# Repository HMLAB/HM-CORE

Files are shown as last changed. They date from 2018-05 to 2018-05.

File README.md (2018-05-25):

# 开源ZYNQ平台，加速你的创想
### Open source ZYNQ platform, accelerate your creativity.

1. Open Source PCB files for HM-CORE
2. Revision: V180401 - File Created
3. Hardware released under[ CERN OHL version 1.2](https://www.ohwr.org/licenses/cern-ohl/license_versions/v1.2 " CERN OHL version 1.2")
4. Forked and changed from https://github.com/AnttiLukats/HackaZynq
5. For more information, please visit: https://www.openzynq.org

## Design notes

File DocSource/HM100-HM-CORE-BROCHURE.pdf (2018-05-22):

HM-CORE Brochure

Powered by HMLAB (http://www.hm-lab.com/)

# HM-CORE

## 一段简单介绍

HM-CORE开源SOC硬件平台由德国Trenz Electronic进行开源原理图和PCB板图设计，HMLAB进 行重设计和分发制造，并继续保持开源，以让更多人以更容易的途经接触到Xilinx ZYNQ SOC平 台。板载的XC7Z010芯片集成双核ARM Cortex-A9处理器和Artix-7 FPGA逻辑资源，使其成为一 款理想的轻量级科研/教育/商用平台，适合将你的智能算法移植到嵌入式智能设备上。

## 不同平台的配置

HM-CORE产品线拥有多个版本以满足不同场景的需求。
| HM-CORE-A | HM-CORE-B
SOC | XC7Z010 | XC7Z010
PS | Dual-core ARM Cortex-A9 MPCore™ with CoreSight™ | Dual-core ARM Cortex-A9 MPCore™ with CoreSight™
PL | Artix-7 FPGA | Artix-7 FPGA
DDR | LPDDR2 64MB | DDR3L 512MB
USB | Hi-Speed USB2.0 ULPI Transceiver | Hi-Speed USB2.0 ULPI Transceiver
SD | MicroSD Card socket | MicroSD Card socket
FLASH | SPI Flash Memory 16MB | SPI Flash Memory 16MB
JTAG | On-board USB JTAG | On-board USB JTAG
I/O | 23 FPGA I/O's available on board-to-board connectors | 23 FPGA I/O's available on board-to-board connectors
UART | On-board USB UART | On-board USB UART
SIZE | 50.80mm x 68.58mm | 50.80mm x 68.58mm
LICENCE | CERN Open Hardware Licence 1.2 | CERN Open Hardware Licence 1.2

HM-CORE Brochure

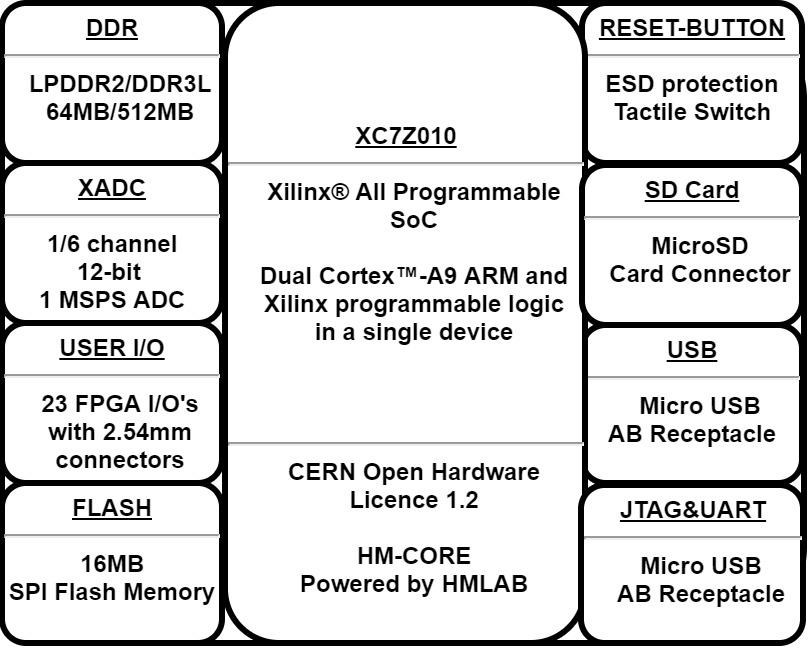
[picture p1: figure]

Powered by HMLAB (http://www.hm-lab.com/)

## 了解你的板卡资源

HM-CORE开源SOC硬件平台采用Arduino外形结构，板载Zynq-7010芯片、64/512MB DDR内存 芯片、16MB固态FLASH配置芯片、MicroSD卡插槽、MicroUSB OTG接口、板载JTAG调试器和U ART接口、微型复位键、LED指示灯和通过2.54mm接插件引出的23个用户I/O引脚。

## 应用到不同场景

IP和智能相机 | 汽车驾驶员辅助，驾驶员信息和信息娱乐
加密货币算法加解密 | 工业电机控制，工业网络
图像视频处理、无人驾驶、嵌入式视觉 | 广播相机
智能音箱热词响应 | 医疗诊断和成像
深度神经网络、机器学习、人工智能 | LTE无线电和基带

## 立即开始你的设计

现在获取你的HM-CORE开发套件
登陆网址: www.hm-lab.com/hm-core获取更多信息
For more information, please visit: www.hm-lab.com/hm-core

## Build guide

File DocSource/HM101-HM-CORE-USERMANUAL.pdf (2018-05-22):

HM-CORE Usermanual

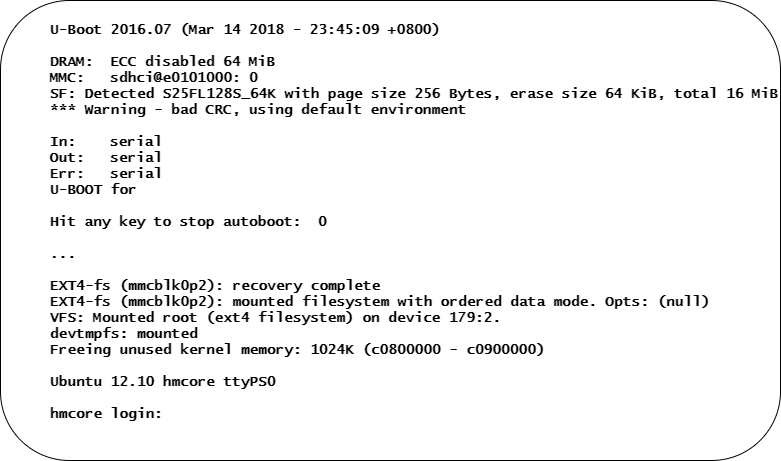
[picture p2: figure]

Powered by HMLAB (http://www.hm-lab.com/)

# HM-CORE

## 立即开箱测试

1通过USB连接线将HM-CORE连接到你的计算机

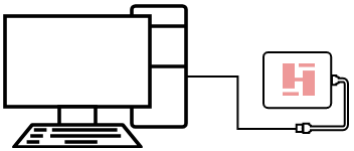
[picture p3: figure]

HM-CORE默认内置固件可以点亮呼吸灯，并启动Linux操作系统。

2 使用串口连接到HM-CORE的系统控制台

打开串口软件(Windows系统首次使用需要安装驱动程序)，确保串口设置（波特率115200，数据 (http://www.hm-lab.com/hm-core/data/CDM21228_Setup.zip) 位8，停止位1，校验无，流控无）正确，若看不到启动打印信息，可以尝试发送回车或重新启动板 卡。成功连接后输入用户名: root 密码: root，即可登录系统。

## 了解你拥有的资源

HM-CORE开源SOC硬件平台采用Arduino外形结构，板载Zynq-7010芯片、64/512MB DDR内存 芯片、16MB固态FLASH配置芯片、MicroSD卡插槽、MicroUSB OTG接口、板载JTAG调试器和U ART接口、微型复位键、LED指示灯和通过2.54mm接插件引出的23个用户I/O引脚。

ZYNQ SOC


Zynq AP SoC(型号：xc7z010clg225-1)芯片主要由两部分组成：Processing System (PS)和Pro grammable Logic (PL)。

PS | Processor Core: Dual-Core ARM Cortex-A9 MPCore with CoreSight L1 Cache: 32 KB Instruction, 32 KB Data per processor L2 Cache: 512 KB On-Chip Memory: 256 KB External Memory Support: DDR3, DDR3L, DDR2, LPDDR2 External Memory Support: 2x Quad-SPI, NAND, NOR DMA Channels: 8 (4 dedicated to Programmable logic) Peripherals: 2x UART, 2x CAN 2.0B, 2x I2C, 2x SPI, 4x 32b GPIO
PL | 7 Series PL Equivalent: Artix-7 FPGA Logic Cells: 28K Look-Up Tables (LUTs): 17,600 Flip-Flops: 35,200

Total Block RAM(# 36Kb Blocks): 2.1Mb(60)
DSP Slices: 80
Analog Mixed Signal (AMS) / XADC(2) 2x 12 bit, MSPS ADCs with up to 17 Differential Inputs

PS DDR
HM-CORE-A PS端的DDR(型号：MT42L32M16D1AB-25 IT:A)采用Micron® 64MB Automoti ve Mobile LPDDR2 SDRAM，用于存储掉电可丢失的数据，通常作为内存使用。
Memory Type | LPDDR2
Effective DRAM IC Bus Width | 16 Bit
ECC | Disabled
Burst Length | 8
Memory Clock Frequency | 400
DRAM Device Capacity | 512MBits
Speed Bin | LPDDR2 800
Bank Address Count(Bits) | 2
Row Address Count(Bits) | 13
Col Address Count(Bits) | 10
CAS Latency(cycles) | 6
CAS Write Latency(cycles) | NA
RAS to CAS Delay(cycles) | 8
Precharge Time(cycles) | 7
tRC(ns) | 48.91
tTASmin(ns) | 34.0
tFAW(ns) | 25

HM-CORE-B PS端的DDR(型号：MT41J256M16 RE-125)采用Micron® 512MB low-voltage ve rsion of the 1.5V DDR3 SDRAM device，用于存储掉电可丢失的数据，通常作为内存使用。

Memory Type | DDR 3(Low Voltage)
Effective DRAM IC Bus Width | 16 Bit
ECC | Disabled
Burst Length | 8

Memory Clock Frequency | 533.333333
DRAM Device Capacity | 4096MBits
Speed Bin | DDR3_1066F
Bank Address Count(Bits) | 3
Row Address Count(Bits) | 15
Col Address Count(Bits) | 10
CAS Latency(cycles) | 7
CAS Write Latency(cycles) | 6
RAS to CAS Delay(cycles) | 7
Precharge Time(cycles) | 7
tRC(ns) | 48.91
tTASmin(ns) | 35.0
tFAW(ns) | 40.0

USB
USB接口PHY芯片(型号：USB3320C-EZK)是带有ULPI接口的高度集成的全功能高速USB 2.0收发器， 用于连接USB移动设备，如U盘、无线网卡等。
Version | USB 2.0
Support | OTG, high-speed, full-speed, and low-speed
Interface | Micro-B

UART & JTAG
UART接口采用USB转UART&JTAG接口芯片(型号：FT2232H)将UART接口和JTAG接口集成在一 个MicroUSB接口上，用于系统调试和监控(使用这个二合一接口需要安装相应驱动程序)。
Default baud rate | 115200(up to 1 Mb/s)
Driver | FTDI Virtual COM Port (VCP)
Standard | IEEE Std 1149.1 Compatible Test Interface
Mode | Cascaded JTAG for PS & PL

RESET BUTTON
复位按键(型号：KMS221GLFS)采用一款微型SMT侧面开关，连接到了ZYNQ SOC的POR_B管 脚，可用于系统复位。
Polarity | Active Low
Connect pin | POR_B

MicroSD SOCKET
MicroSD卡插槽(型号：104031-0811)自带插入检测功能，连接到ZYNQ PS的SD卡控制器上，用 于存储设备树、内核文件、文件系统和用户数据等。
Interface | MicroSD
Style | Push-Pull
Height | 1.42mm

QSPI FLASH
FLASH(型号：S25FL127S)为QSPI接口，容量为16MB，用于存储系统启动代码(BOOT.bin)等数 据。
Interface | SPI with Multi-I/O
Density | 128 Mbits (16 Mbytes)
Cycling Endurance | 100,000 Program-Erase Cycles per sector, minimum
Data Retention | 20 Year Data Retention, minimum

XADC
板载6选1模拟信号通道选择芯片(型号：CD74HC4051D)和电压转换芯片(型号：AD8031ART)， 将采集信号接入XADC，用于简单的模数信号采集转换。
ADC | 12-bit
Sample rates | 1 MSPS

Bandwidths | 500KHz
Voltage range | 0~3.3V

I/O
共有23个用户I/O和6个电源引脚通过2.54mm连接器引出，可用于连接扩展板卡或主控制线路板 (如图像、语音采集传感器，无人机飞控平台等)。
External reset | 1
PL user I/O | 12
Analog input | 6
Interface | IIC-2, UART-2
Power supply | 3.3V-2, 5V-1, GND-3

BOOT
HM-CORE通过固定的电阻连接进行BOOT启动模式控制，默认从QSPI Flash启动，启动前需要将 你的BOOT.bin文件通过Xilinx SDK工具烧写进QSPI Flash。
FSBL(BOOT.bin) | QSPI Flash
PL(BOOT.bin) | QSPI Flash
U-Boot(BOOT.bin) | QSPI Flash
Kernel(image.ub) | SD Card(boot)
Device Tree(system.dtb) | SD Card(boot)
Root Filesystem | SD Card(rootfs)

## 准备进行开发

1 从官网下载board files文件，拷贝到你的Vivado安装路径下： (http://www.hm-lab.com/hm-core/data/hmcore_board_files_v1.0.zip)

Example:
Windows: C:\Xilinx\Vivado\2016.4\data\boards\board_files
Linux: /home/Xilinx/Vivado/2016.4/data/boards/board_files

2 从官网下载配套BIST测试工程及系统相关文件 (http://www.hm-lab.com/hm-core/data/hmcore_bist_v1.0.zip)(U-BOOT、 (http://www.hm-lab.com/hm-core/data/hmcore_u-boot_v1.0.zip)设备树、 (http://www.hm-lab.com/hm-core/data/hmcore_devicetree_v1.0.zip)内核、 (http://www.hm-lab.com/hm-core/data/hmcore_kernel_v1.0.zip)文件系统)，用于检查 (http://www.hm-lab.com/hm-core/data/hmcore_rootfs_v1.0.zip) 资源及组件是否正常。

## BIST工程

将BIST(Build-In Self Test)工程文件解压后，Block design中由两个IP组成：ZYNQ和LED，ZYNQ IP用于运行裸机程序或嵌入式Linux操作系统；LED IP通过PL引脚连接呼吸灯。

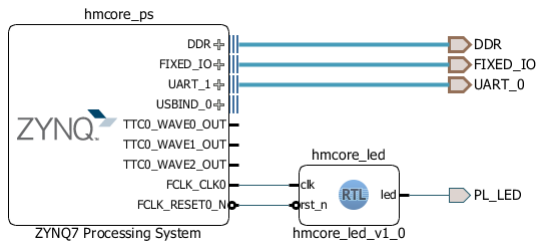
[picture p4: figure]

了解BIST工程

ZYNQ IP配置了运行内存DDR、系统控制台交互UART、USB 2.0接口。

LED IP用于驱动呼吸灯，双机该IP可修改呼吸频率，其时钟和复位引脚来自FCLK0(100MHz)。

从BIST工程中提取ZYNQ配置文件用于新的设计工程

1 打开BIST工程，进入Block Design，双击打开ZYNQ IP，Presets > Save Configuration > Pres et Name: hmcore-zynq & File name: hmcore-zynq.tcl点击确定，导出配置文件。

2 新建设计工程，新建Block Design，新建ZYNQ IP，从菜单栏Presets > Apply Configuration > 选择hmcore-zynq.tcl，导入配置文件。

## 编写SDK程序

从BIST工程菜单: Files > Launch SDK，打开Xilinx SDK开发环境，可以看到如下测试DEMO:

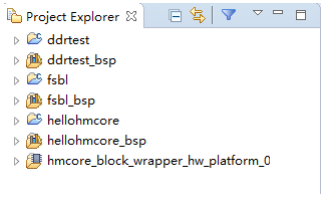
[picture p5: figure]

Hello HM-CORE

自带测试DEMO
通过USB连接线缆连接HM-CORE，右键单击hellohmcore，选择Run As > Launch on Hardware (System Debuger)，观察串口控制台打印信息。

新建测试DEMO
通过USB连接线缆连接HM-CORE，打开Xilinx SDK开发软件，通过点击File > New > Application Project，输入工程名称并选择Hello World模板，右键单击新建的工程，选择Run As > Launch o n Hardware(System Debuger)，观察串口控制台打印信息。

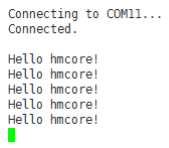
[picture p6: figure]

测试DDR

自带测试DEMO
通过USB连接线缆连接HM-CORE，右键单击ddrtest，选择Run As > Launch on Hardware(Syst em Debuger)，观察串口控制台打印信息。

新建测试DEMO
通过USB连接线缆连接HM-CORE，打开Xilinx SDK开发软件，通过点击File > New > Application Project，输入工程名称并选择Memory Tests模板，右键单击新建的工程，选择Run As > Launch on Hardware(System Debuger)，观察串口控制台打印信息。

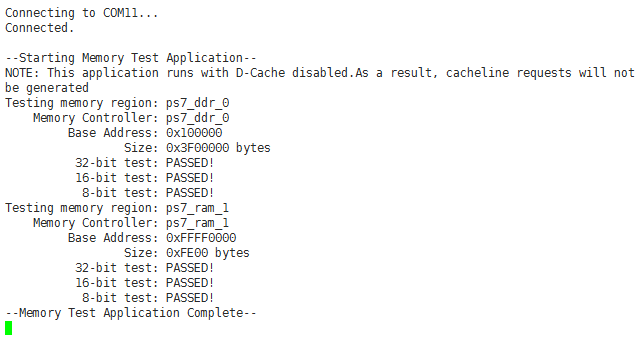
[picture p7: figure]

## 开始运行Linux系统

搭建Petalinux开发环境

下载Xilinx PetaLinux安装包，按照UG1144中的步骤进行安装。最后通过命令"source (https://www.xilinx.com/support/download/index.html/content/xilinx/en/downloadNav/embedded-design-tools.html) /home/lik w/Xilinx/petalinux/settings.sh"验证安装完成。

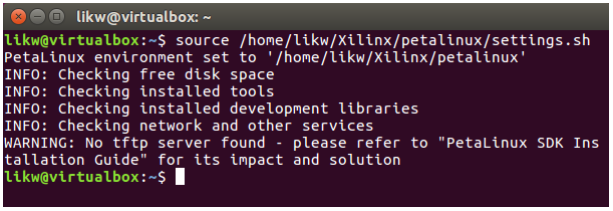
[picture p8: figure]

下载HM-CORE PetaLinux工程

从官网下载PetaLinux工程文件，解压到你的PetaLinux工作目录：

通过命令"petalinux-config"进行基本配置；
通过命令"petalinux-config -c kernel"进行内核配置；
通过命令"petalinux-bulid"进行工程编译；
通过命令"petalinux-package --boot --format BIN --fsbl ./images/linux/zynq_fsbl.elf --fpga . /images/linux/hmcore_block_wrapper.bit --u-boot --force"生成BOOT.bin。

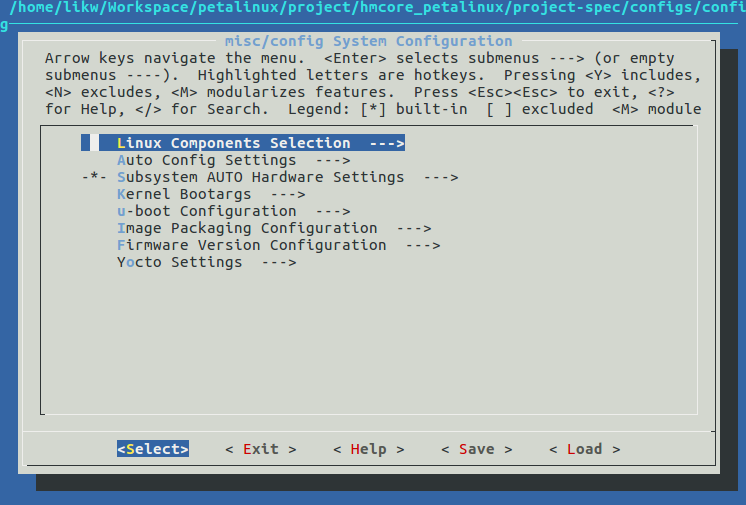
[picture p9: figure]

新建Petalinux工程

从BIST或你的Vivado设计工程hmcore_bist.sdk文件夹中复制hmcore_block_wrapper.hdf文件到 PetaLinux工作目录：

通过命令"petalinux-config --get-hw-description=/home/likw/Workspace/petalinux/project /hmcore_petalinux"新建工程；

通过命令"petalinux-config"进行基本配置；
通过命令"petalinux-config -c kernel"进行内核配置；
通过命令"petalinux-bulid"进行工程编译；

最后通过命令"petalinux-package --boot --format BIN --fsbl ./images/linux/zynq_fsbl.elf --fp ga ./images/linux/hmcore_block_wrapper.bit --u-boot --force"生成BOOT.bin。

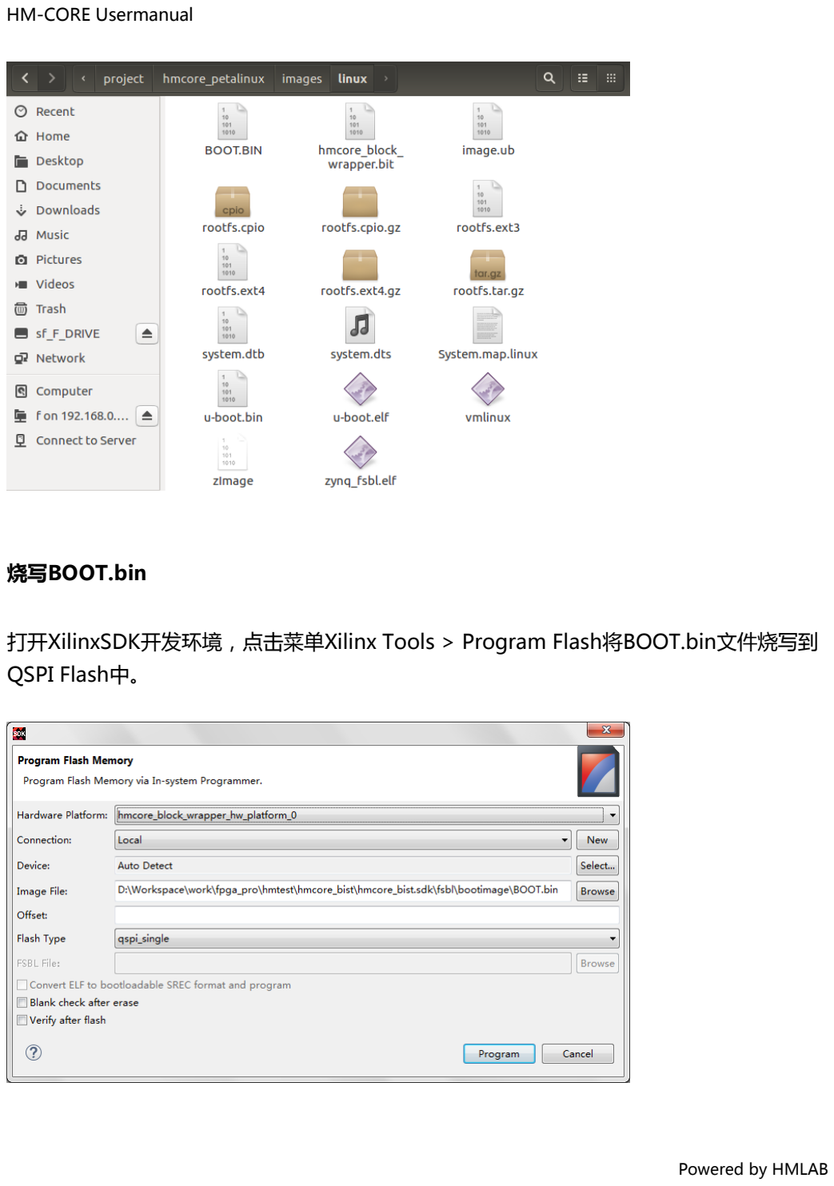
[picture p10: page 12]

烧写BOOT.bin

打开XilinxSDK开发环境，点击菜单Xilinx Tools > Program Flash将BOOT.bin文件烧写到 QSPI Flash中。

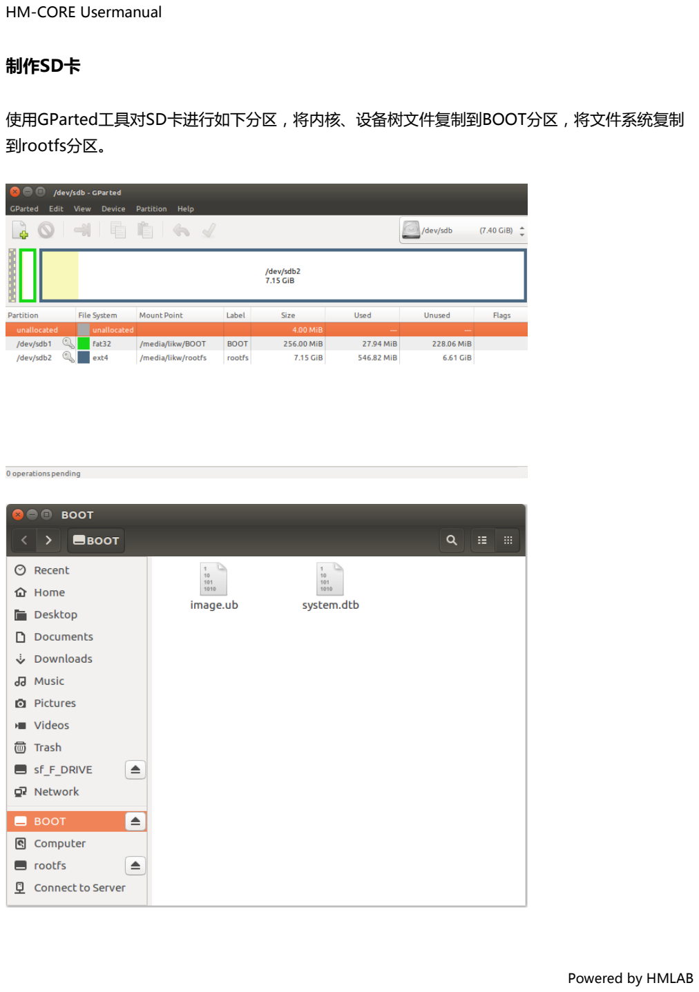
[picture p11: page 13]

制作SD卡

使用GParted工具对SD卡进行如下分区，将内核、设备树文件复制到BOOT分区，将文件系统复制 到rootfs分区。

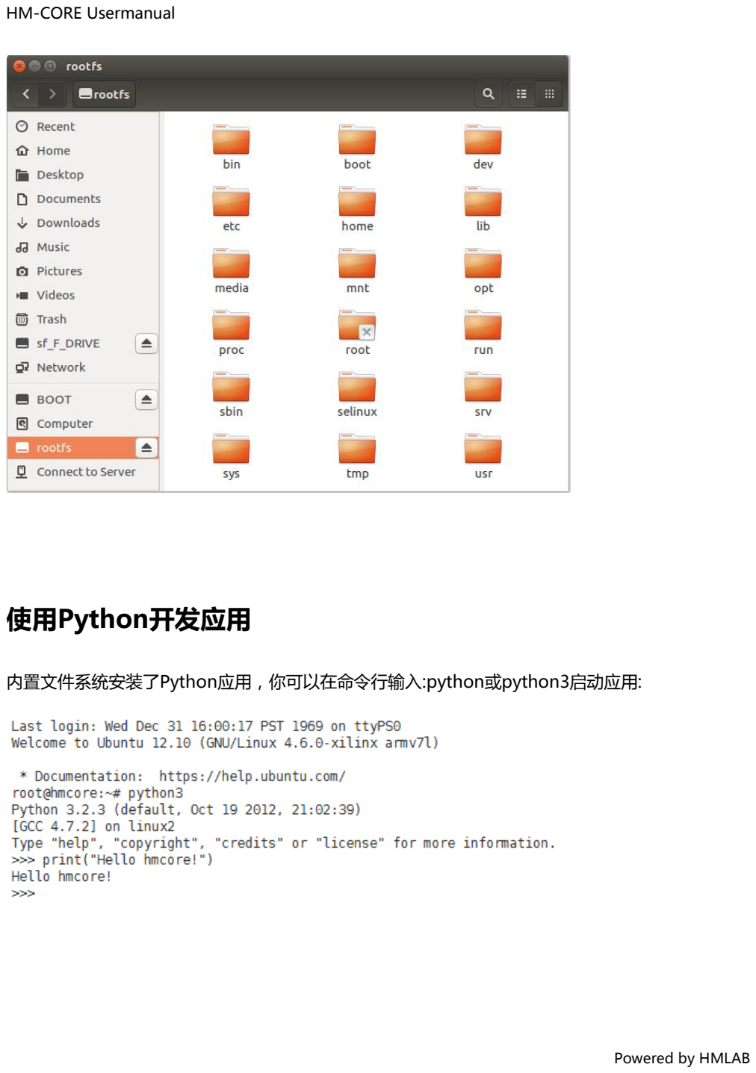
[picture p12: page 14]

## 使用Python开发应用

内置文件系统安装了Python应用，你可以在命令行输入:python或python3启动应用:

## 需要注意的地方

板载CLG225封装的ZYNQ芯片无法直接从SD卡直接启动，你需要将BOOT.BIN文件烧写到板载QS PI FLASH中启动FSBL、PL逻辑配置流(bit文件)和U-BOOT，然后从SD卡启动内核、加载设备树和 文件系统；

HM-CORE可以使用USB形式的无线网卡连接你的WIFI网络与互联网进行连接，但首先需要安装与 你的USB无线网卡适配的驱动程序。

## 应用到不同场景

IP和智能相机 | 汽车驾驶员辅助，驾驶员信息和信息娱乐
加密货币算法加解密 | 工业电机控制，工业网络
图像视频处理、无人驾驶、嵌入式视觉 | 广播相机
智能音箱热词响应 | 医疗诊断和成像
深度神经网络、机器学习、人工智能 | LTE无线电和基带

## 立即开始你的设计

现在获取你的HM-CORE开发套件
登陆网址: www.hm-lab.com/hm-core获取更多信息
For more information, please visit: www.hm-lab.com/hm-core

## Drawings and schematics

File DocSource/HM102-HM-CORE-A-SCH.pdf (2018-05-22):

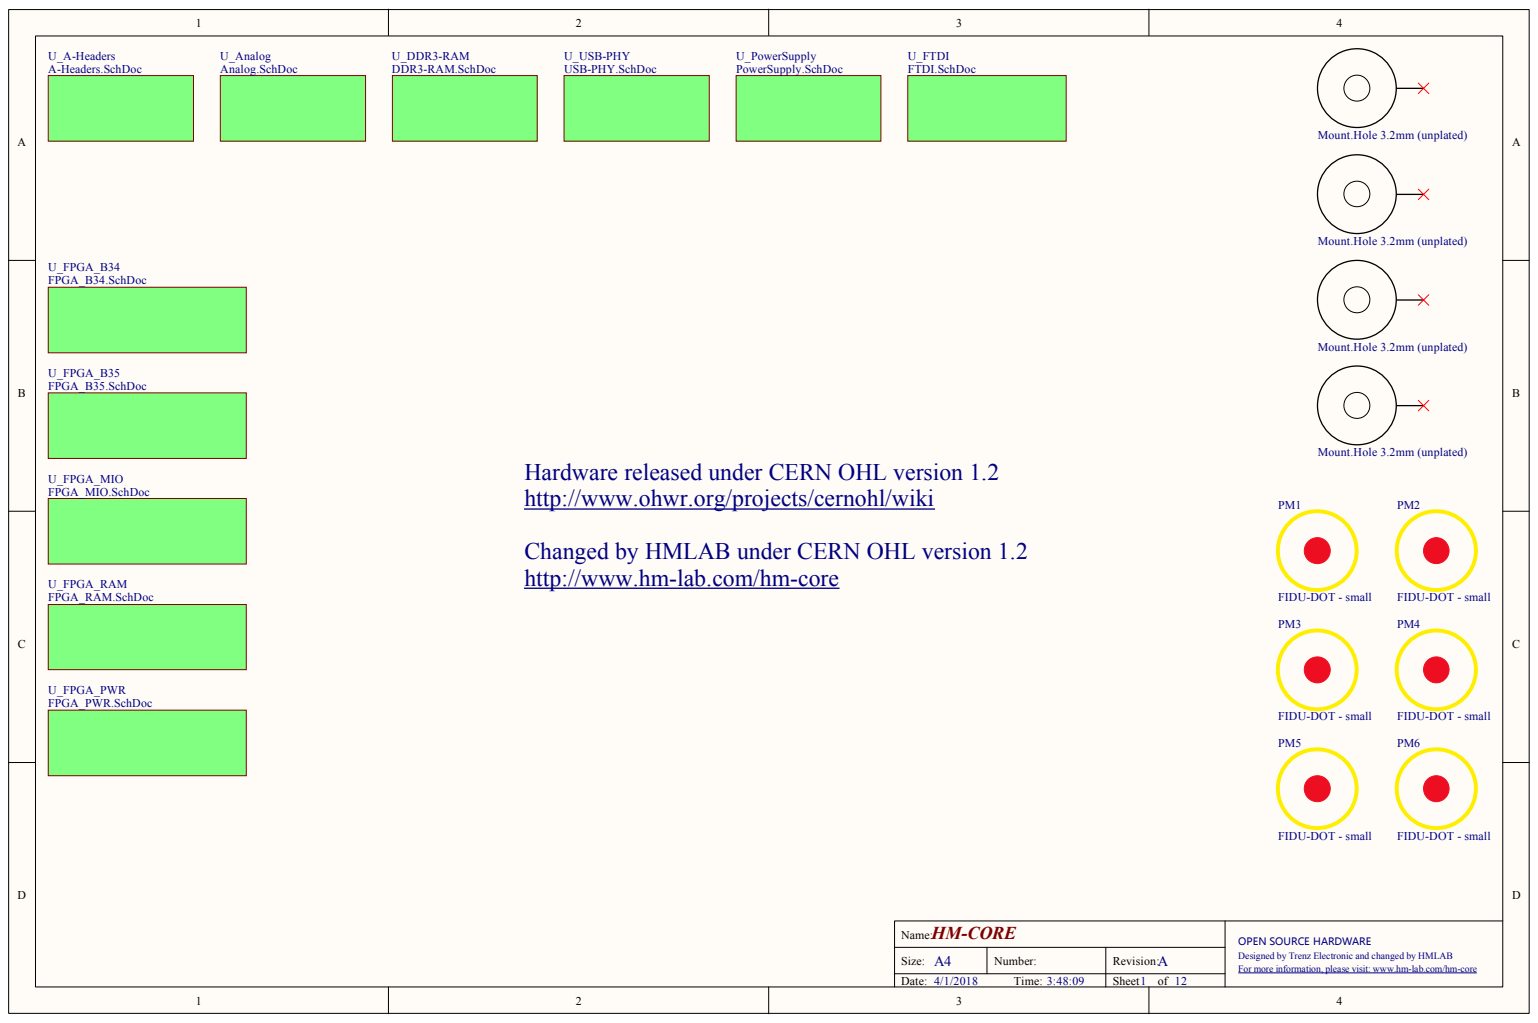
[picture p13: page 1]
HM-CORE; Name:; Size:; Number:; Date:; Revision:; Time:; Sheet; For more information, please visit: www.hm-lab.com/hm-core; U_A-Headers A-Headers.SchDoc; U_Analog Analog.SchDoc; U_DDR3-RAM DDR3-RAM.SchDoc; U_FPGA_B34 FPGA_B34.SchDoc; U_FPGA_B35 FPGA_B35.SchDoc; U_FPGA_MIO FPGA_MIO.SchDoc; U_FPGA_PWR FPGA_PWR.SchDoc; U_FPGA_RAM FPGA_RAM.SchDoc; U_FTDI FTDI.SchDoc; U_PowerSupply PowerSupply.SchDoc

U_USB-PHY
USB-PHY.SchDoc

Mount.Hole 3.2mm (unplated)

Hardware released under CERN OHL version 1.2
http://www.ohwr.org/projects/cernohl/wiki

Changed by HMLAB under CERN OHL version 1.2
http://www.hm-lab.com/hm-core

FIDU-DOT - small

OPEN SOURCE HARDWARE
Designed by Trenz Electronic and changed by HMLAB

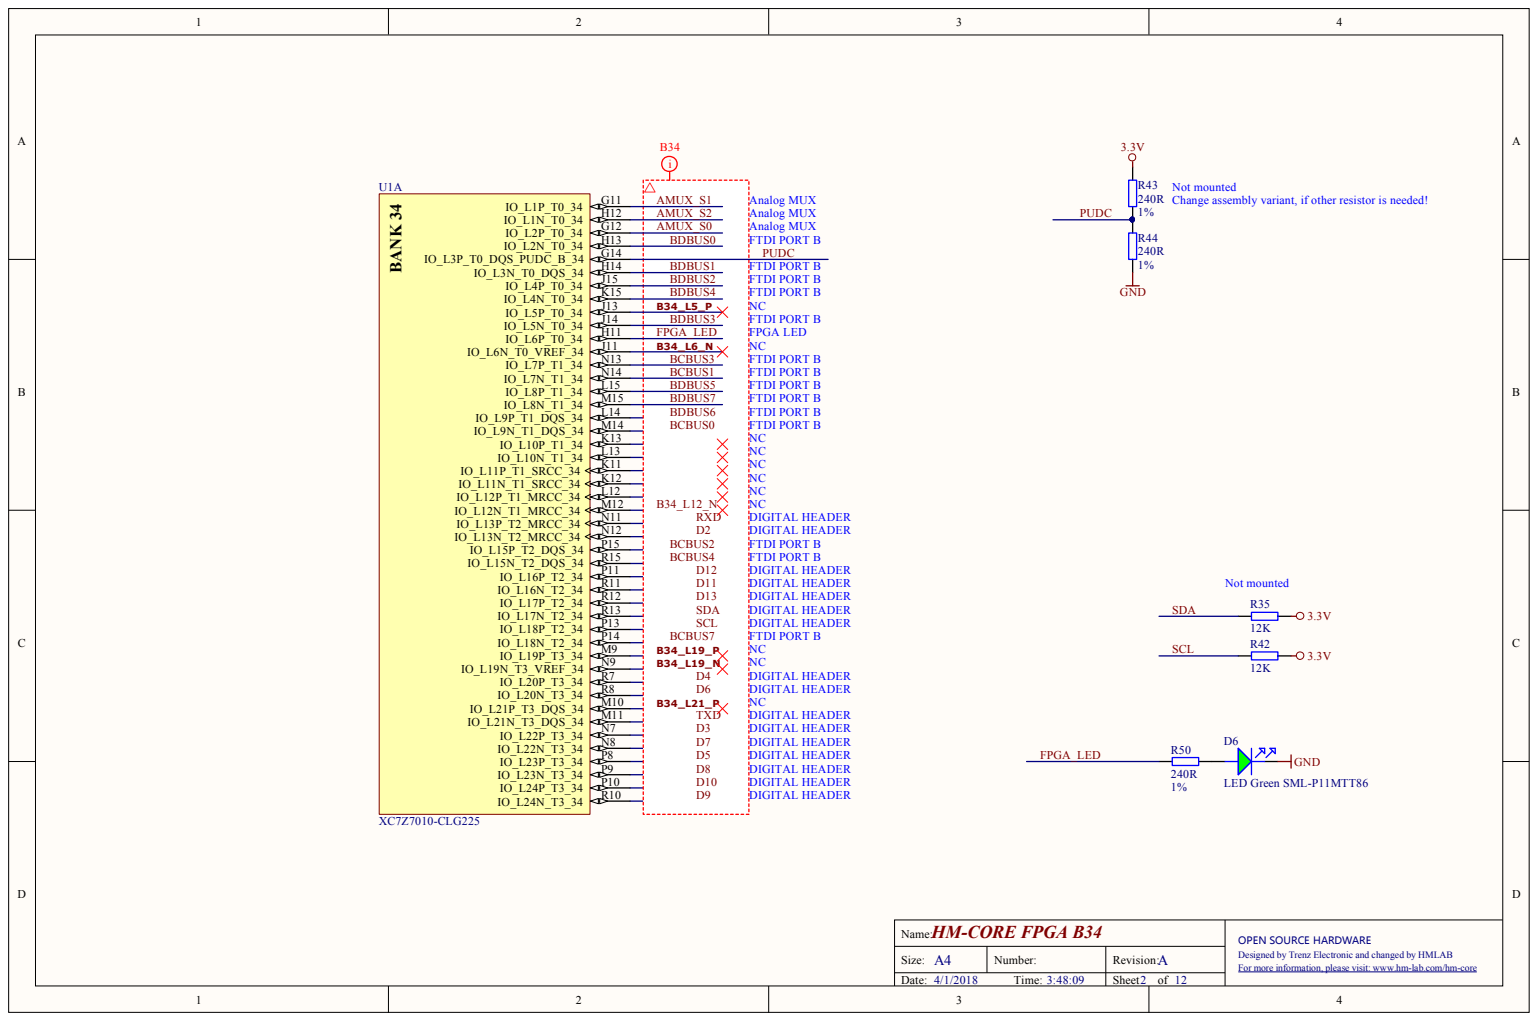
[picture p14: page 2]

Not mounted
Change assembly variant, if other resistor is needed!

OPEN SOURCE HARDWARE
Designed by Trenz Electronic and changed by HMLAB

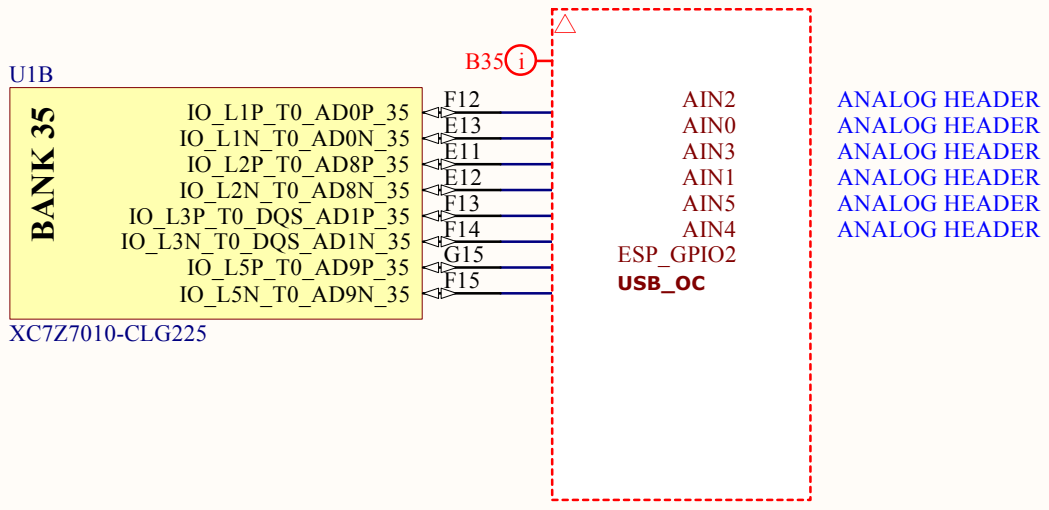
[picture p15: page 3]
Size:; Number:; Revision:; For more information, please visit: www.hm-lab.com/hm-core; IO_L3N_T0_DQS_AD1N_35; F14 IO_L3P_T0_DQS_AD1P_35; BANK 35; XC7Z7010-CLG225; ANALOG HEADER ANALOG HEADER ANALOG HEADER ANALOG HEADER; ANALOG HEADER; AIN0; AIN1; AIN2; AIN3; AIN4; AIN5; USB_OC; ESP_GPIO2

HM-CORE FPGA B35
Name:

OPEN SOURCE HARDWARE
Designed by Trenz Electronic and changed by HMLAB

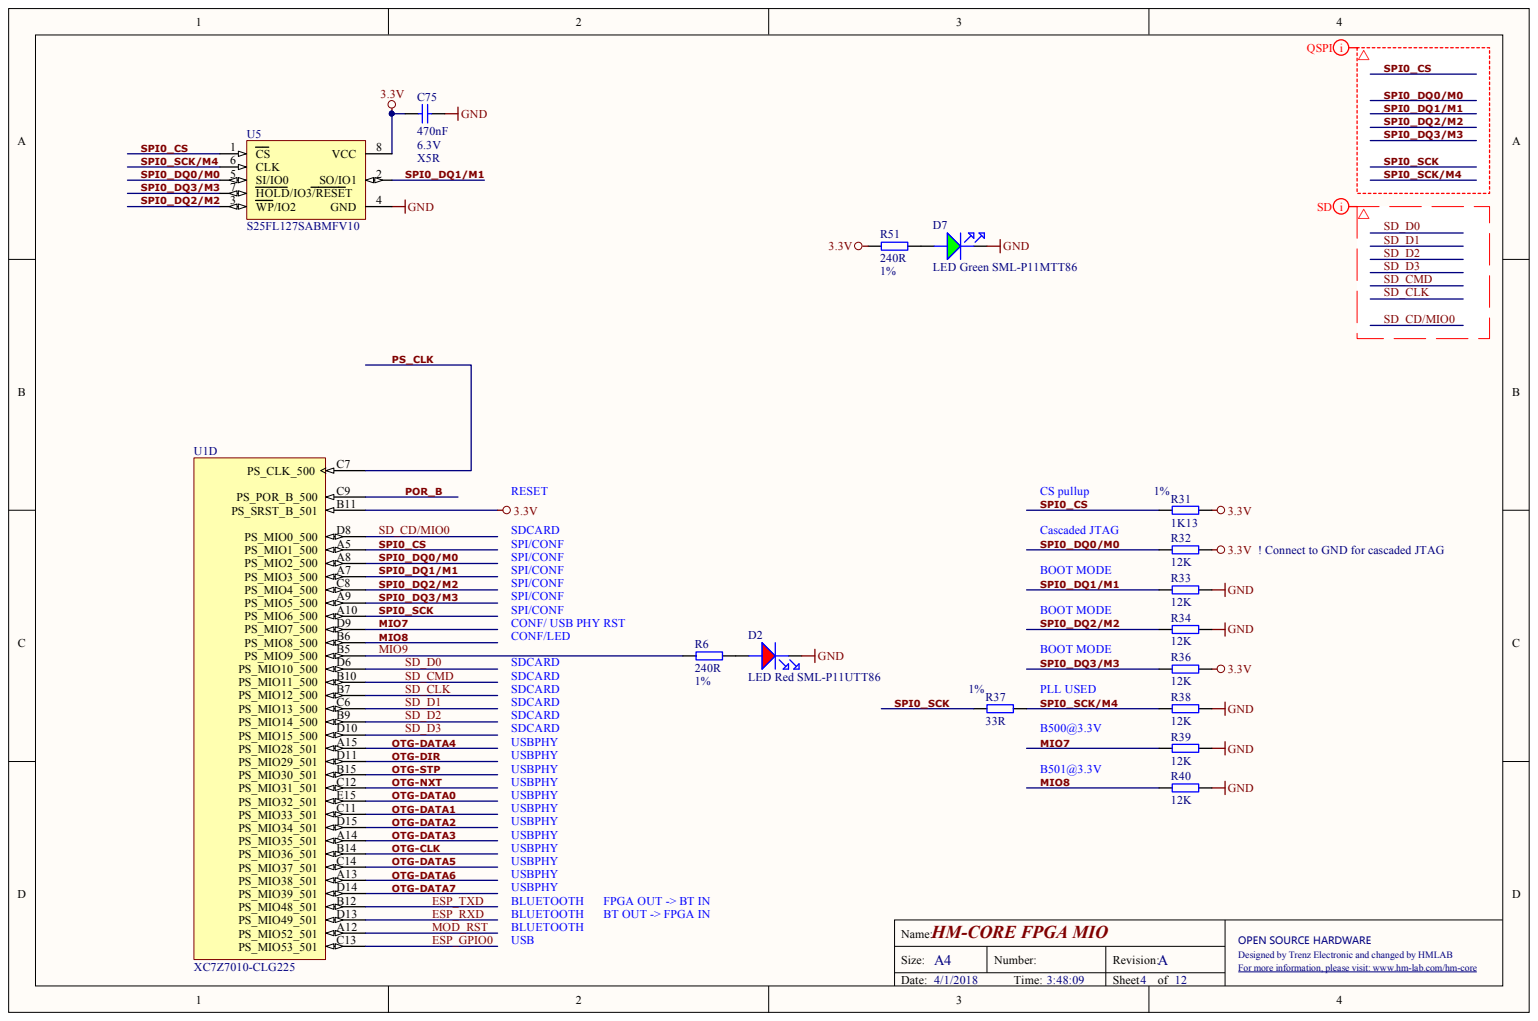
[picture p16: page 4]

! Connect to GND for cascaded JTAG

FPGA OUT -> BT IN
BT OUT -> FPGA IN

HM-CORE FPGA MIO
Name:

OPEN SOURCE HARDWARE
Designed by Trenz Electronic and changed by HMLAB

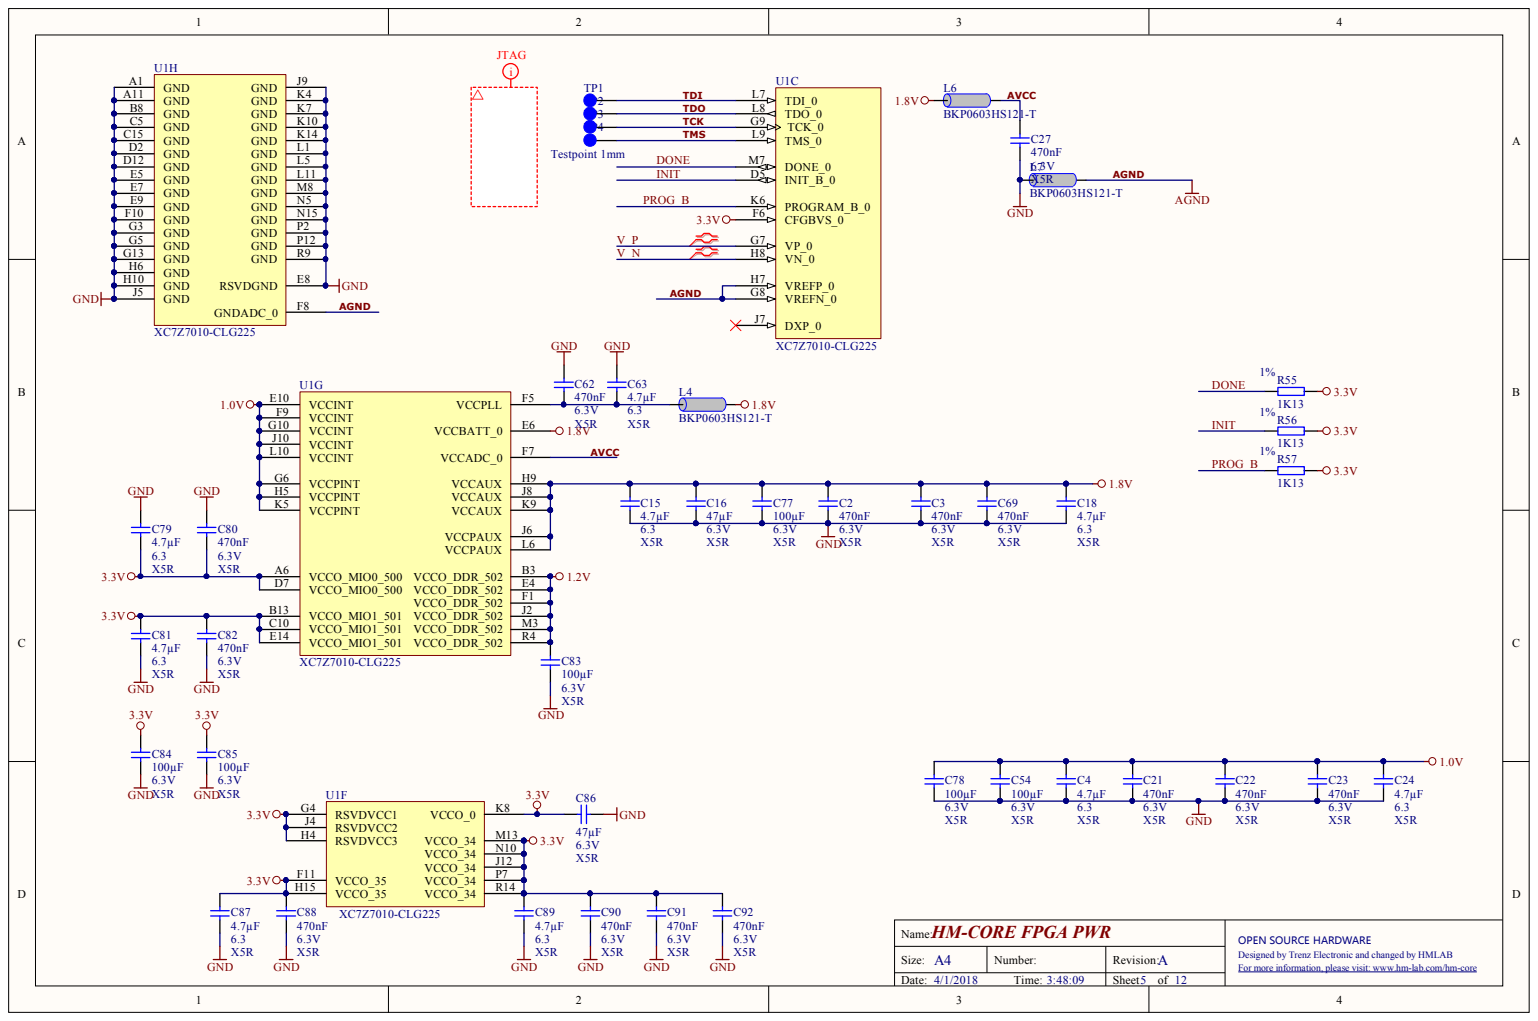
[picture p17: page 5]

HM-CORE FPGA PWR
Name:

OPEN SOURCE HARDWARE
Designed by Trenz Electronic and changed by HMLAB

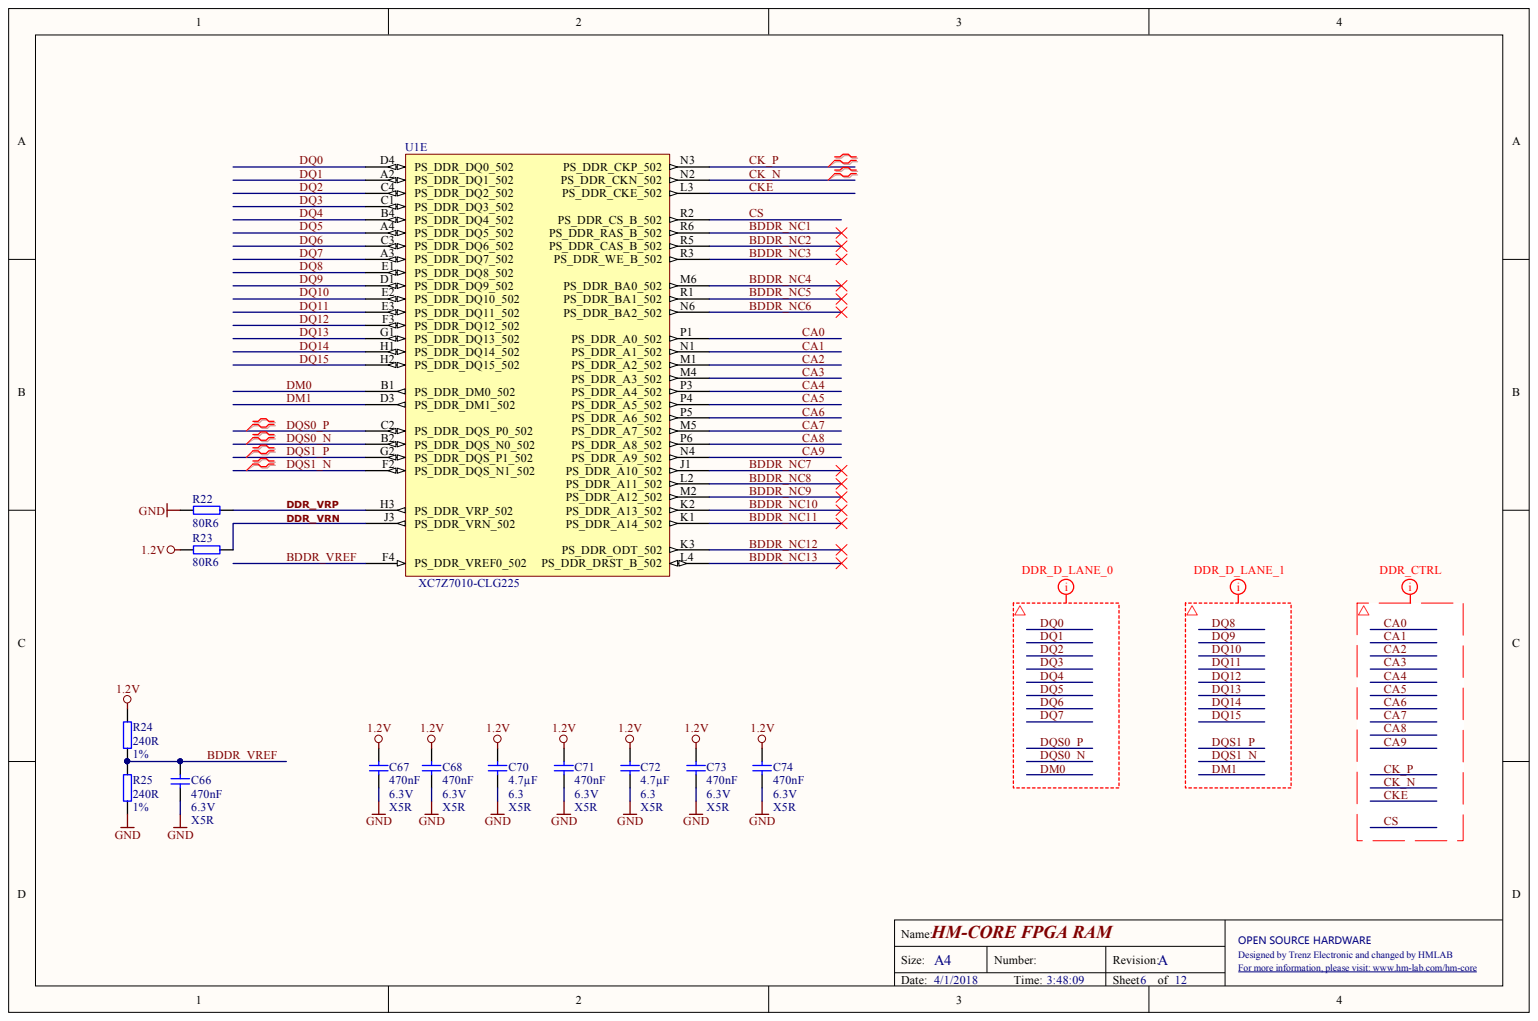
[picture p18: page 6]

HM-CORE FPGA RAM
Name:

OPEN SOURCE HARDWARE
Designed by Trenz Electronic and changed by HMLAB

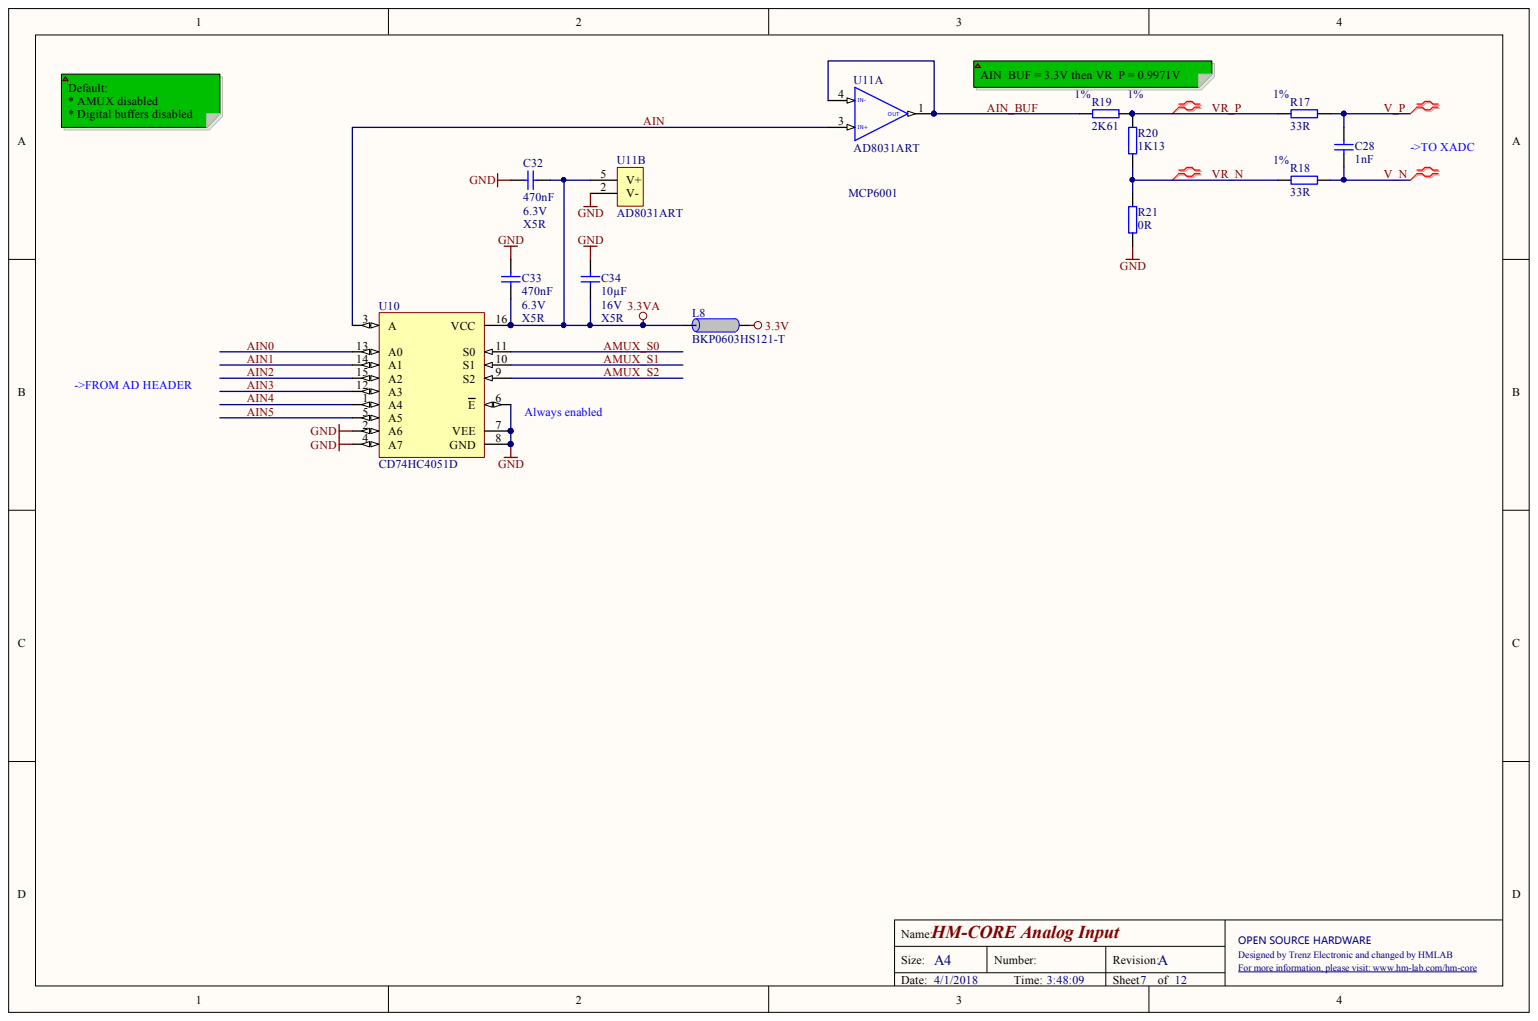
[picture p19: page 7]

HM-CORE Analog Input
Name:

OPEN SOURCE HARDWARE
Designed by Trenz Electronic and changed by HMLAB

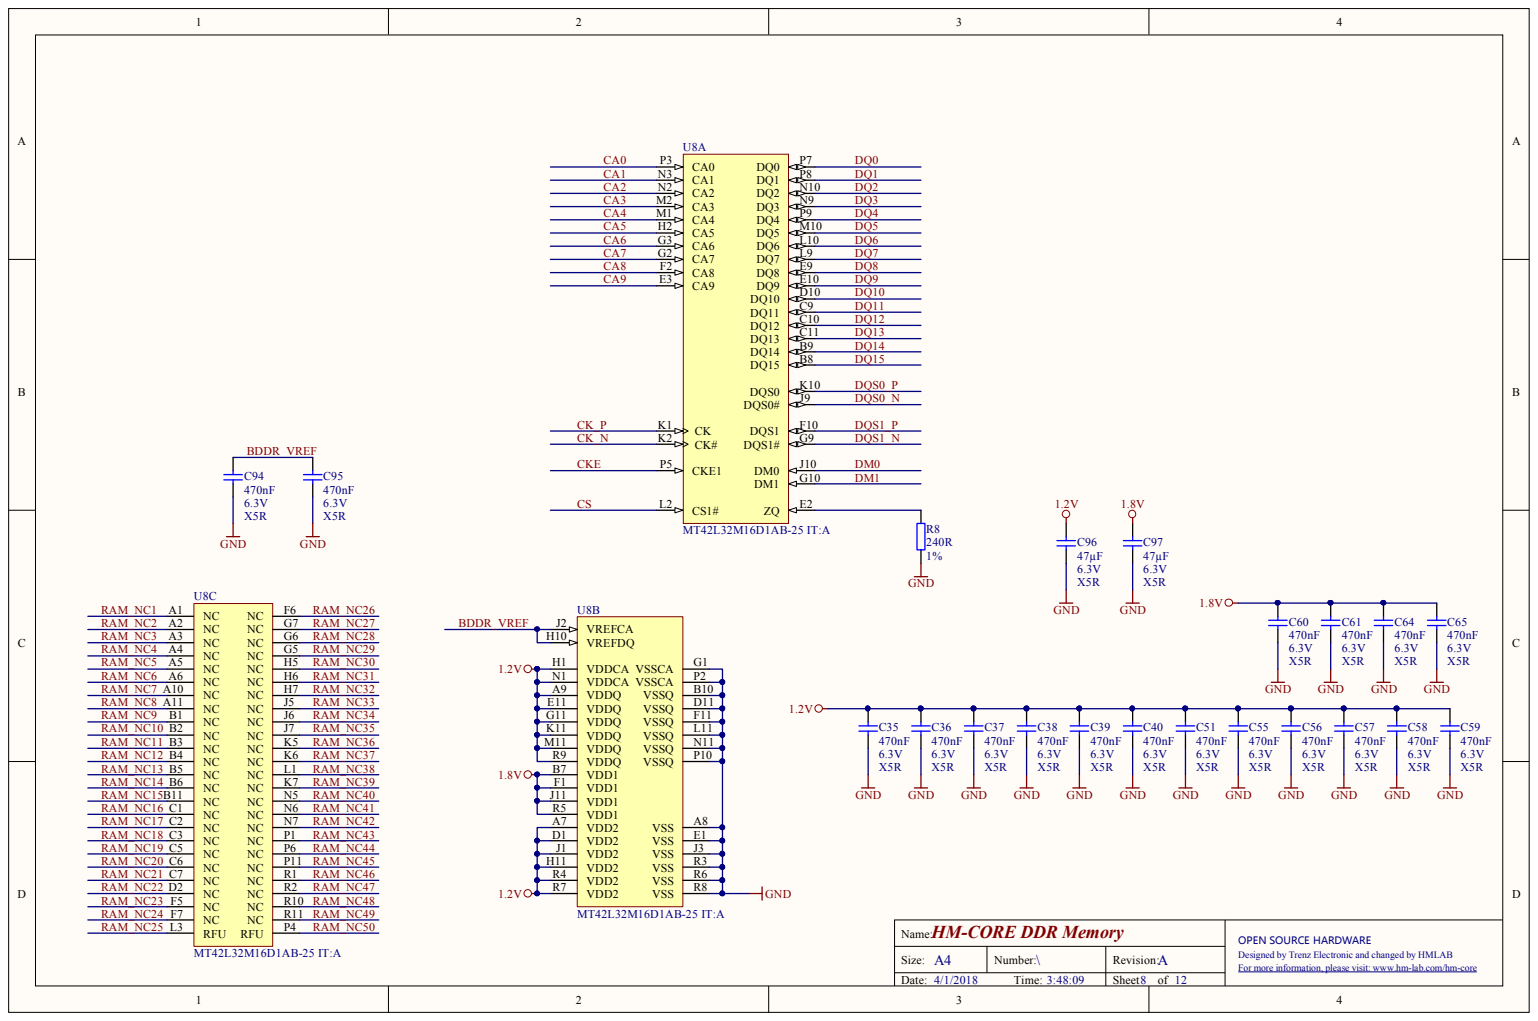
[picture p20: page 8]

HM-CORE DDR Memory
Name:

OPEN SOURCE HARDWARE
Designed by Trenz Electronic and changed by HMLAB

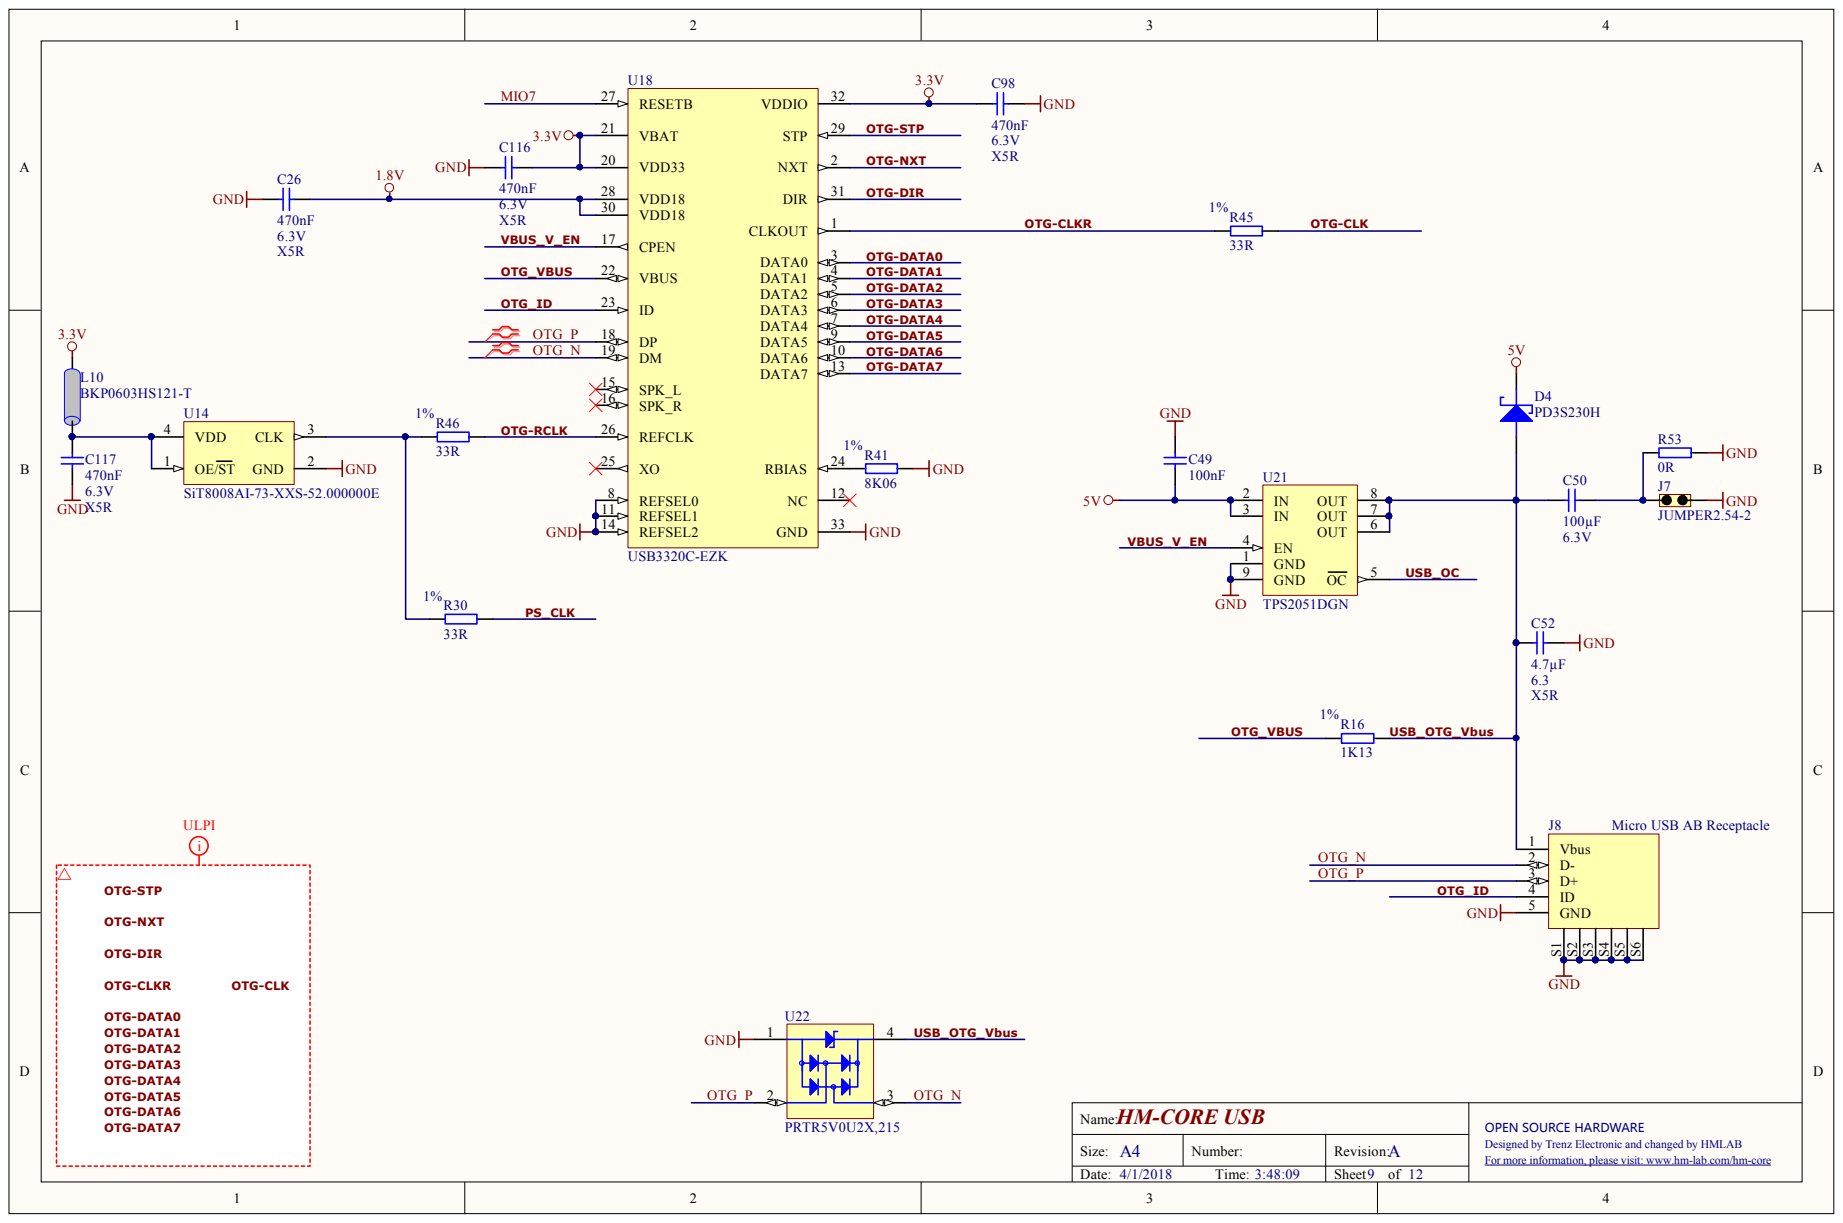
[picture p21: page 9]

OPEN SOURCE HARDWARE
Designed by Trenz Electronic and changed by HMLAB

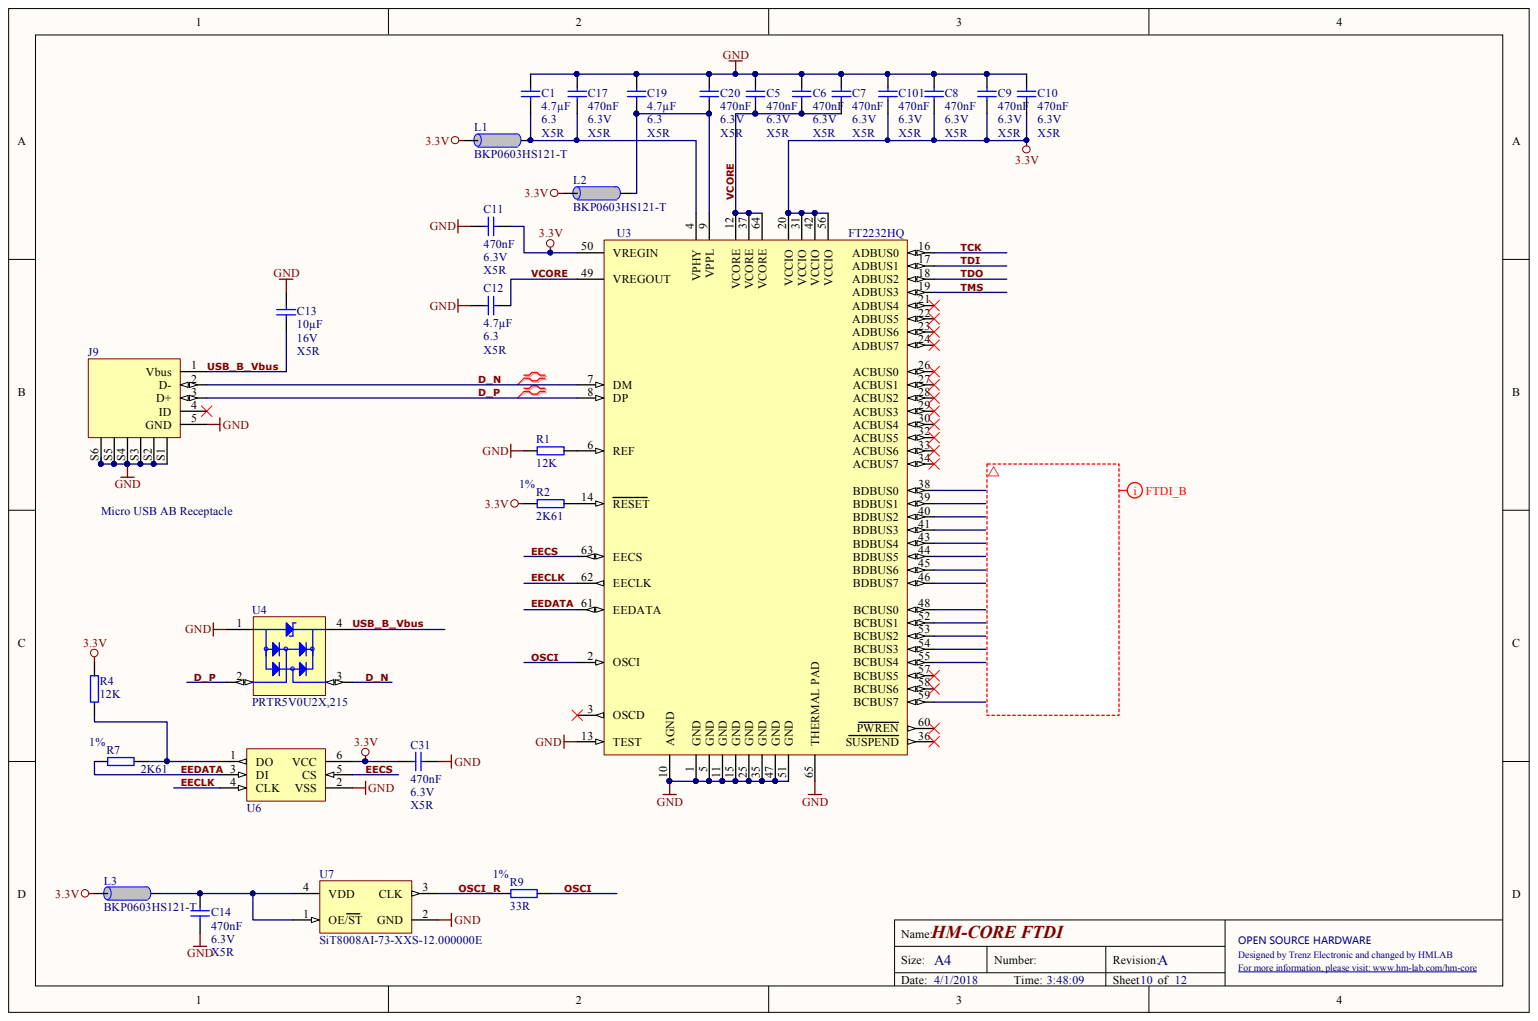
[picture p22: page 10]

Micro USB AB Receptacle

OPEN SOURCE HARDWARE
Designed by Trenz Electronic and changed by HMLAB

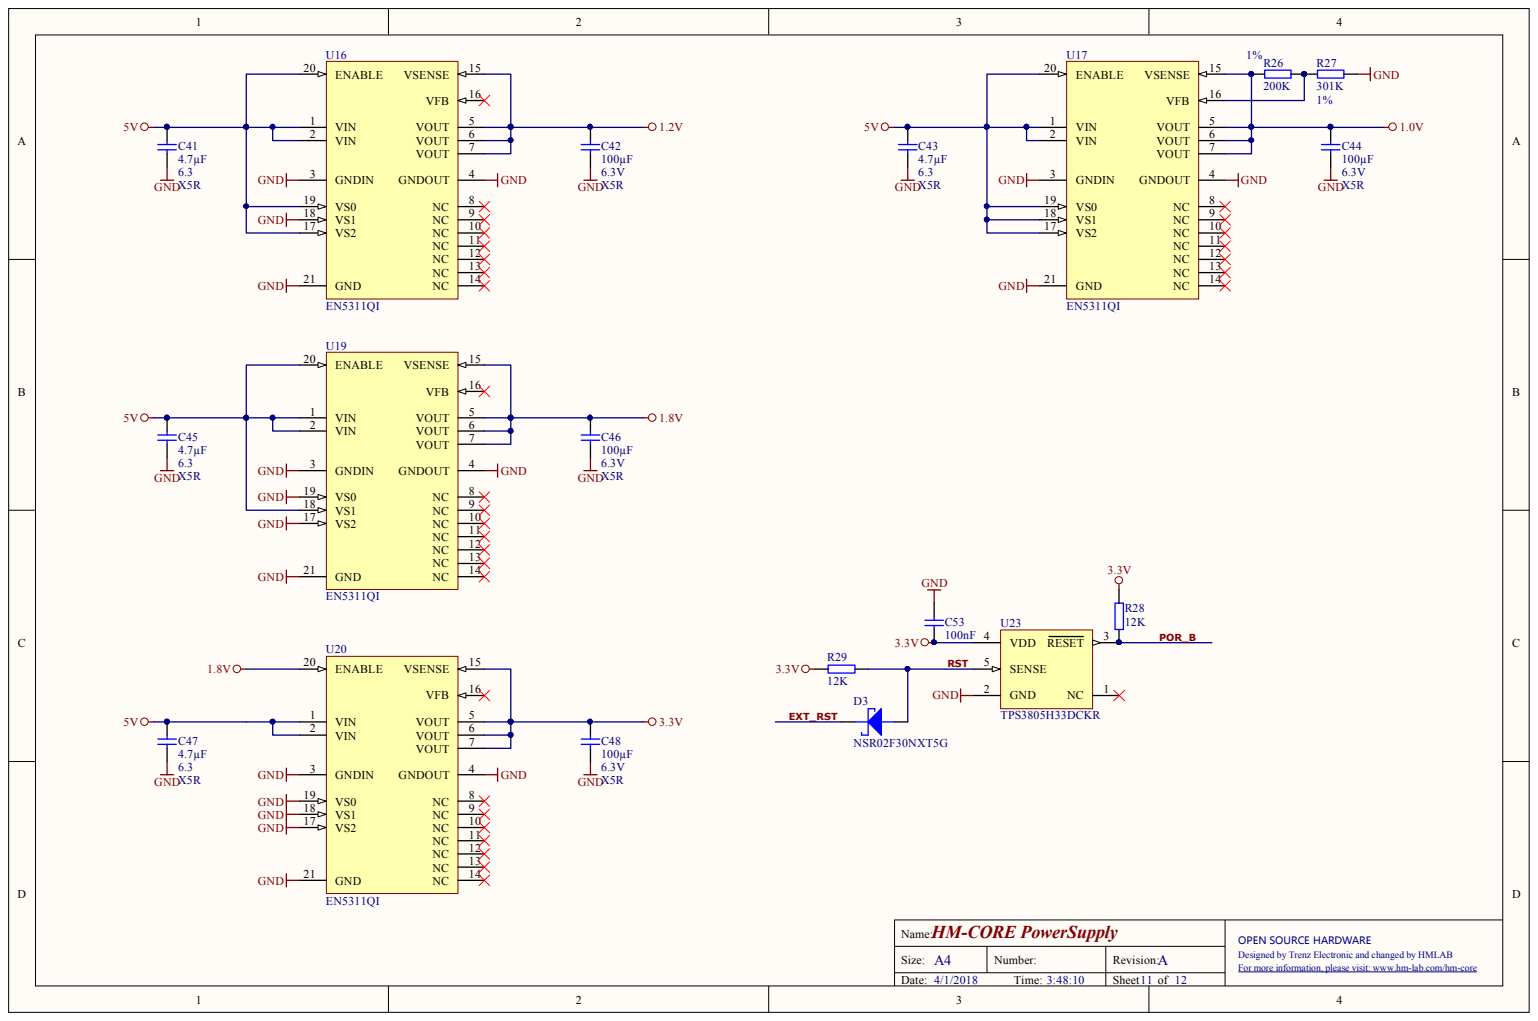
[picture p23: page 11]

OPEN SOURCE HARDWARE
Designed by Trenz Electronic and changed by HMLAB

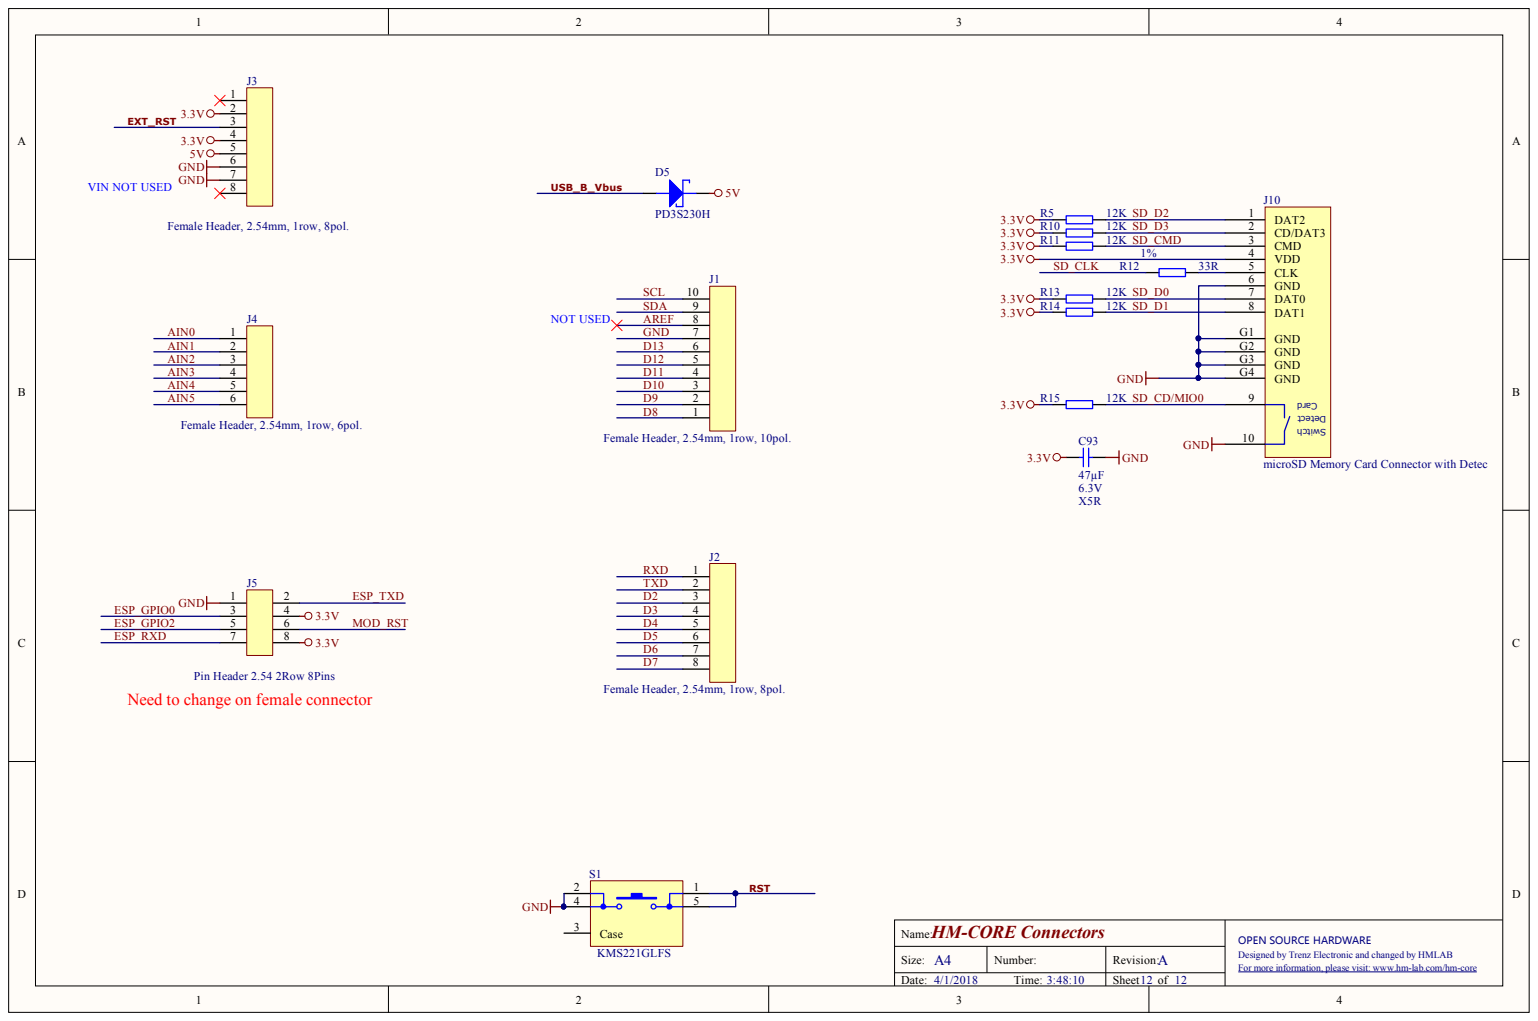
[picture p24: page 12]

microSD Memory Card Connector with Detec

Need to change on female connector

OPEN SOURCE HARDWARE
Designed by Trenz Electronic and changed by HMLAB
